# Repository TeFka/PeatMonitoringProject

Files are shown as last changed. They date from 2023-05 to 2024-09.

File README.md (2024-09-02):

# University group project
# Peat monitoring device
### This is the repository for used for storage of all relevant resources used for the university group project.<br>
### The project involved development of a device that would be placed in a peat and provides measuremetns about the peat state.</br>
### Measurements include:
* Surface elevation - shows how much peat surface changed water in it.</br>
* Water pressure - shows the pressure created by the peat water table.</br>
* Temperature - shows temperature of surroundings around the device.</br>
* Operate for at least 6 months unsupervised and store all data.</br>
### A poster was created for the device:</br>
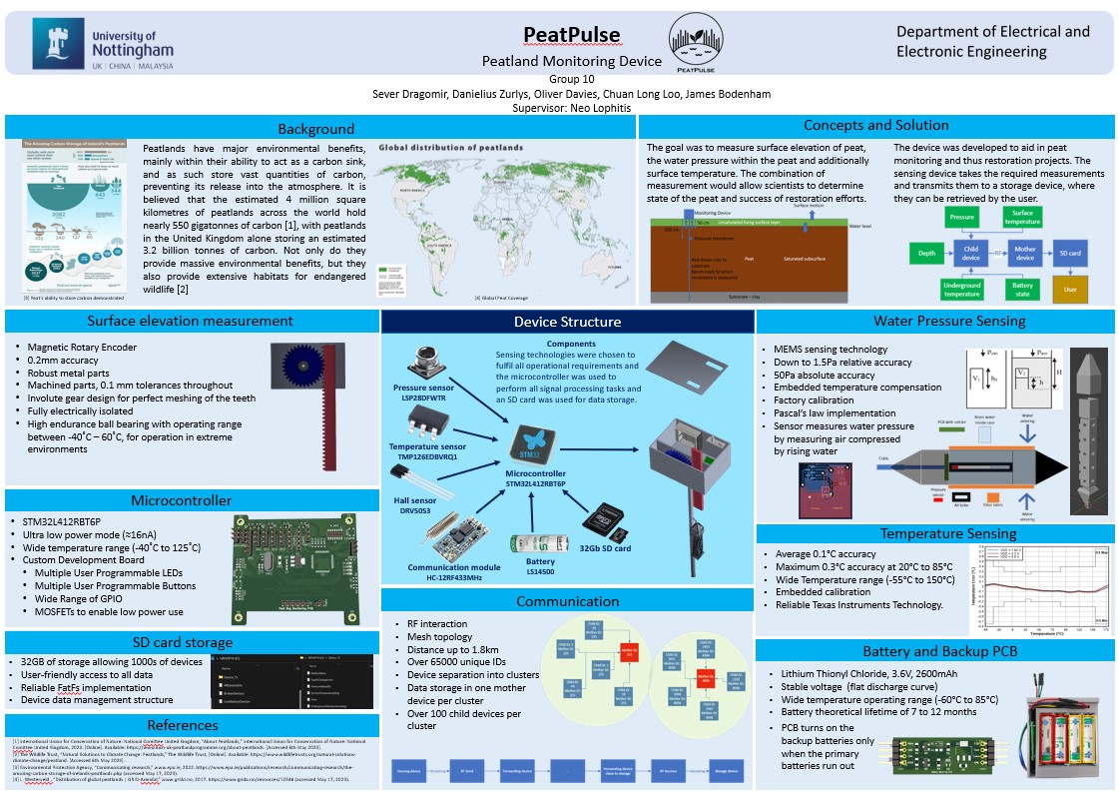
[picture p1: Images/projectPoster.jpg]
The poster of project
</br>
### The respository was created and managed by Danielius Zurlys. Project work done by Danielius Zurlys:<br>
* All embedded software<br>
* Hardware and mechanical designs for pressure sensor<br>
* Hardware and mechanical designs for temperature sensor<br>
### Work done by other group members:<br>
* Oliver Davies - Developed PCB for STM32<br>
* Chuan Loo - Developed PCB for battery control<br>
* Sever Dragomir - Design for main case and elevantion sensor.<br>
* James Bodenham - RF communication hardware choice and logic<br>

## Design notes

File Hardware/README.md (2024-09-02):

# All hardware designs</br>
### Contains all hardware designs which include:</br>
1. Pressure sensor PCB - the PCB is meant to simply host the used presssure sensor and provide easier connections for the user.</br>
2. Batter management system PCB (Created by Chuan Loo) - the battery system allows to reduce battery votlage to acceptable level and switch to the second battery once the first battery is depleted.</br>
3. STM32 PCB (Created by Oliver Davies) - a PCB meant to host the STM32 chip that would control the logic of the whole device.</br>

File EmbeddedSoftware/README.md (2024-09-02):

# All developed embedded software<br>
### Developed by Danielius Zurlys, while colaborating with other team members.<br>
The software is presented as the whole STM32 baord project or as a separate module meant to only cover one functionality of the overall device.

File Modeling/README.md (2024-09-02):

# All modelling work
The repository only includes pressure sensor designs, created by Danielius Zurlys, as other designs were not available.

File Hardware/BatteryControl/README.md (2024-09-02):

# Battery management PCB PCB</br>
### Designed by Chuan Loo</br>
### The PCB is meant to allow efficient and safew usage of batteries. Main functions are:</br>
* Reduce battery voltage to safe levels for the PCB.</br
* Use one battery at a time even if two are connected, when one battery is depleted, only then the PCB starts retrieving power from second battery.</br

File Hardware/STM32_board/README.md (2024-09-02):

# STM32 chip PCB</br>
Designed by Oliver Davies</br>
The main PCB for STM32 chip. Provides SPI, I2C, UART and analogue connections that allow communicaton with all relevant components. Connection to the battery is also availalbe to provide power.</br>

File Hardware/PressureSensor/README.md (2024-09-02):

# Pressure sensor PCB
Developed PCB to host pressure sensor. The used pressure sensor is LPS28DFW (.pdf datasheet file provded).
The sensor is very small and the PCB is meant to enable connection between sensor and standart connections.

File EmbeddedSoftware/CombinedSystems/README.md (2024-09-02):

# Combined STM32 projects<br>
### Covers combined projects, each involving several separate modules. The maind components are:<br>
* Code for Mother device - device meant for data storage.<br>
* Code for Child device - device meant for data grathering.<br>
* Code for remote connector - device meant for data retrieval.<br>
### The overall operation logic goes as follows:<br>
1. The child device gathers data using available sensors.<br>
2. The child device sends data to the mother device using RF communicaton, if the mother device is too far away, other device acts as a proxy.<br>
3. The mother devoce receives the data from child device and saves it into an SD card.<br>
4. The operation repeats itself at specific intervals and for a required amount of time.<br>
5. The user comes to the mother device and uses the remote device to communicate with mother device and the mother device transfers all stored data to the remote.<br>

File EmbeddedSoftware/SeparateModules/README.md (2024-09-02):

# Code for separate modules<br>
### Covers code for separate moduels that would then be used together, the modules include<br>
1. Depth measurement logic - logic for using analogue Hall magnet sensors for surface elevation measurements. The sensors would provide measurements from magnets on the elevation sensor and this way determine the current surface movement. The modeul code includes calibrartion values that are needed for accurate measurements.<br>
2. Pressure sensor interaction module - the code includes C wrapper for STM32 that allows to communicate with LPS28DFW pressure sensor using I2C. Covers all relevant operations an dinteractions with registers.<br>
3. Temperature sensor interaction module - the code includes C wrapper for STM32 that allows to communicate with TMP126-Q1 temperature sensor using I2C. Covers all relevant operations an dinteractions with registers.<br>
4. SD card interacttion module - the code allows to interact with an SD card using basic SPI commands. It is meant to work with FATFS support and can be used directly with a basic SD card adapter.<br>
5. STM32 flash memory inteaction module - the code allows to easilty interact with the STM32 flash memory and store data at specific locations.<br>
6. RF networking logic module - the code allows to automatically handle RF communication logic of the device system. The main feature is the ability for the device to act as a data proxy for another device and this way allowing devives to communicate with further devices. When device sends data, it also sends parameters that allow proxy devices to handle data correctly, such as target device or the number of bounces the data had. The module allows to create the communication network that the system needs.<br>

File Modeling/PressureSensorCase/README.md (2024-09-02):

# Pressure sensor mechanical designs
### Designs include:<br>
1. Direct case - a case that would allow the pressure sensor to sense the underground water pressure directly.<br>
2. Tube case - a case that would allow the pressure sensor to sense the water pressure using compressed air in a tube. The water would rise up the tube and compress the air in the tube, which would then be measured by the pressure sensor. The pressre of compressed air is equal to the water pressure applied at the end of the tube, therefore the approach can provide good results.<br>
<br>
The tube design has potential to increase logevity of the pressure sensor by avoiding the direct contact with acidic and hazardous peat environment, while direct design is simpler and more reliable.<br>

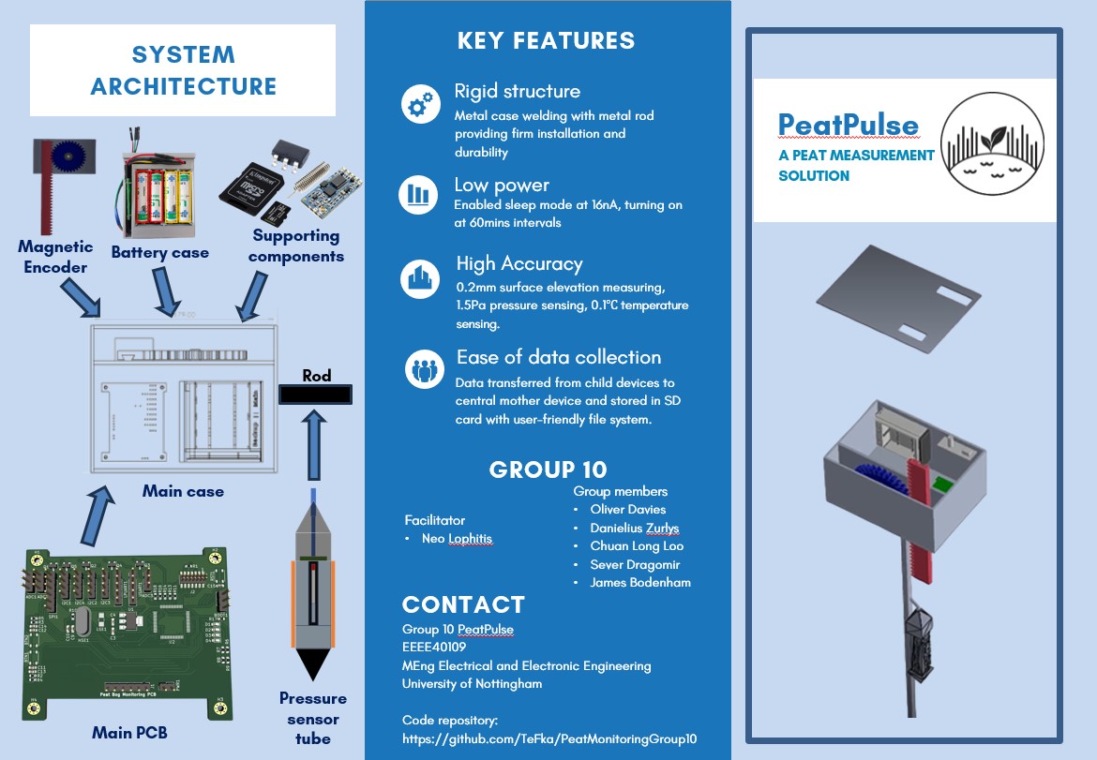
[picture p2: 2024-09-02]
Images/flyerFront.jpg

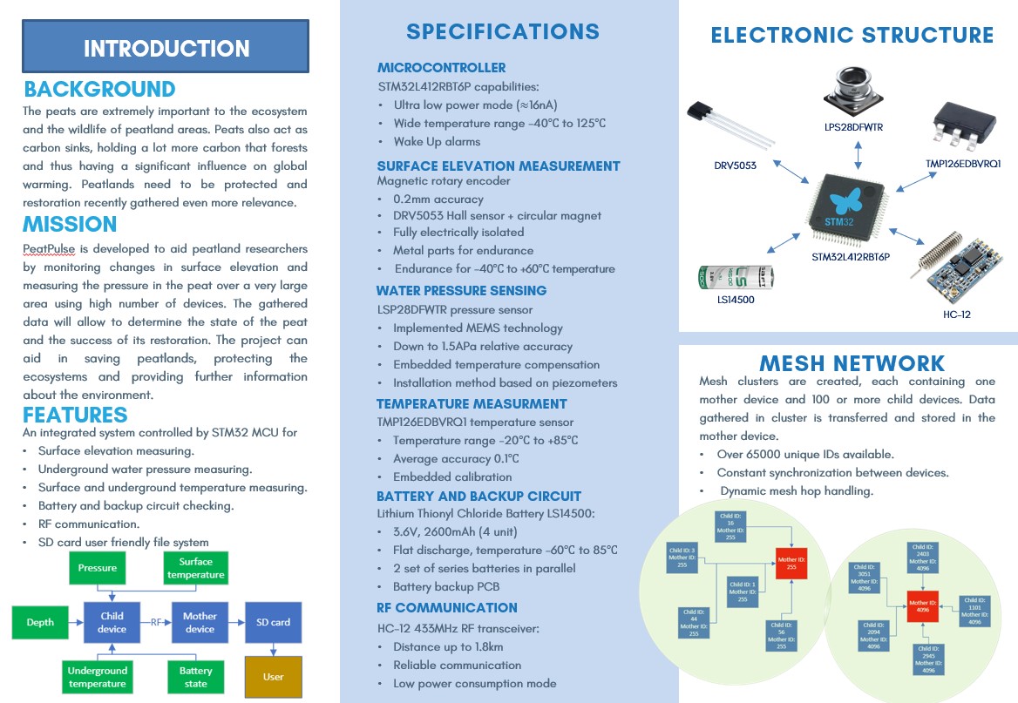
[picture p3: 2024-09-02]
Images/flyerBack.jpg

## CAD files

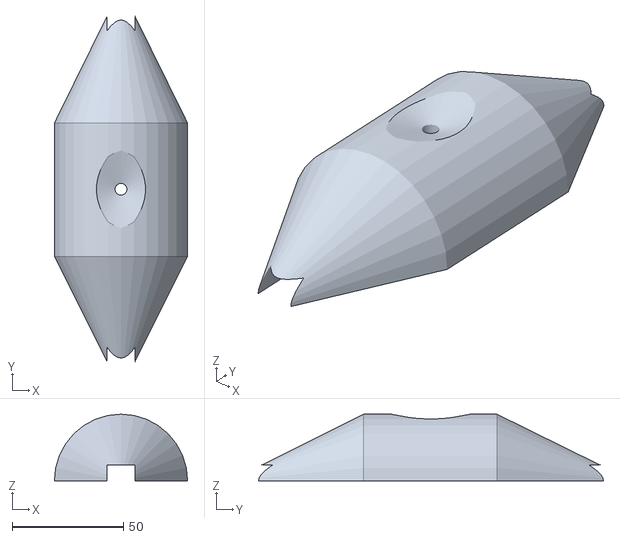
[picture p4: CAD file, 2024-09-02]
Modeling/PressureSensorCase/directCase/directCaseBack.stl
60.0 x 155.3 x 30.0

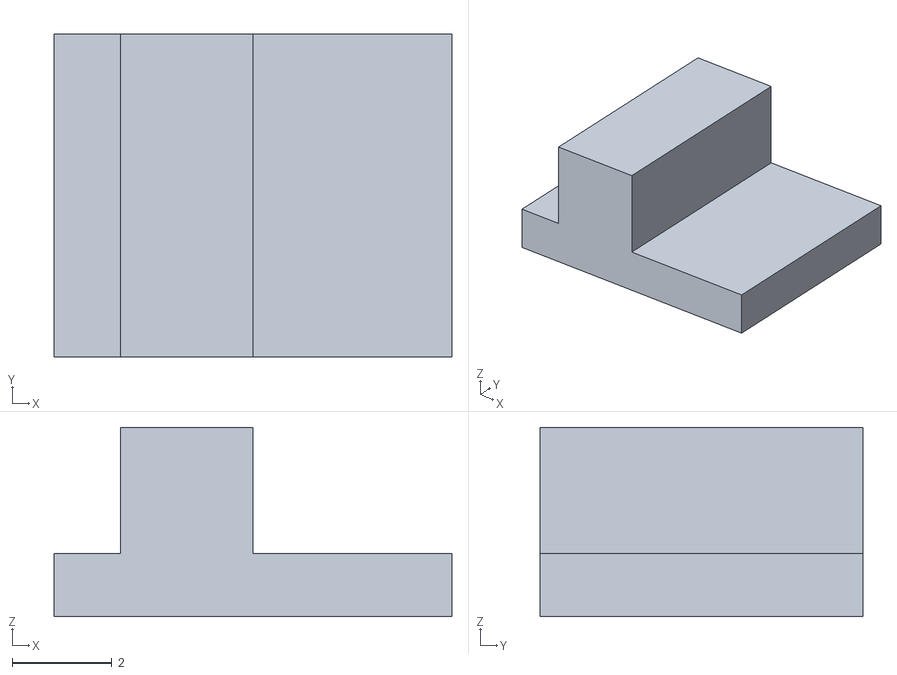
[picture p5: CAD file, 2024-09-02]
Modeling/PressureSensorCase/tubeCase/TubePCBHolder.stl
8.00 x 6.50 x 3.80

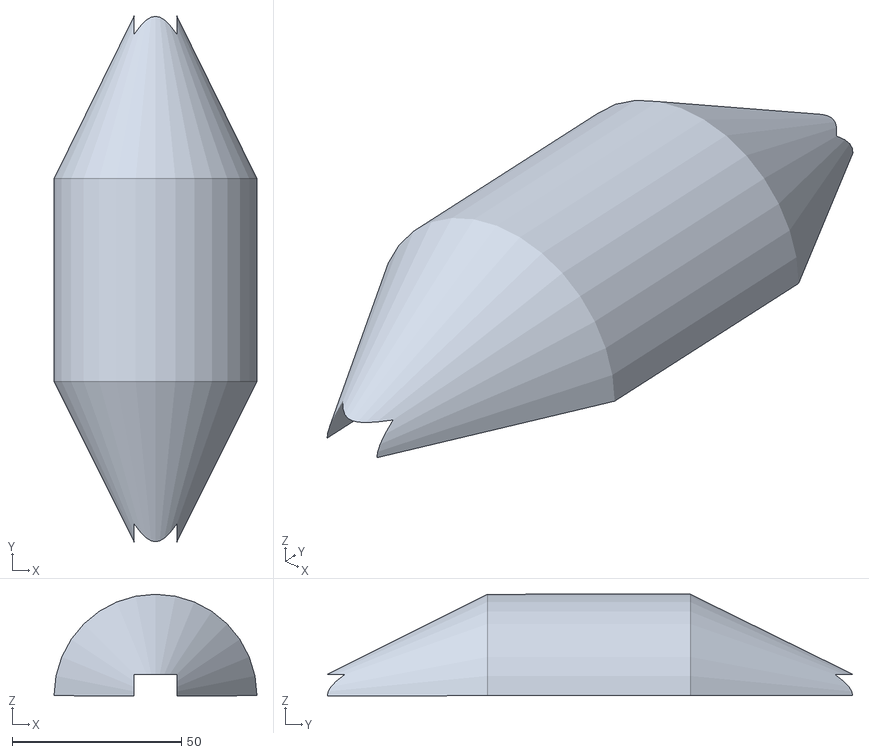
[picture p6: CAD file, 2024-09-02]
Modeling/PressureSensorCase/directCase/directCaseFront.stl
60.0 x 155.3 x 30.0

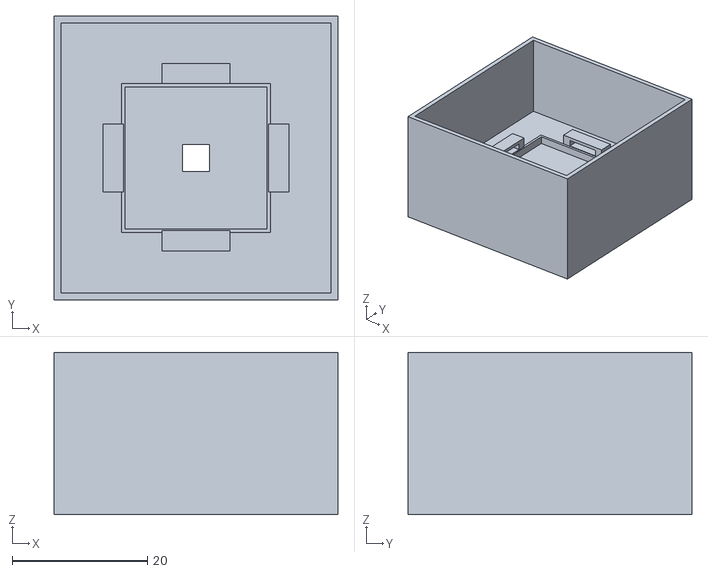
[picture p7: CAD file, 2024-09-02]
Modeling/PressureSensorCase/tubeCase/TubePCBArea.stl
42.0 x 42.0 x 24.0

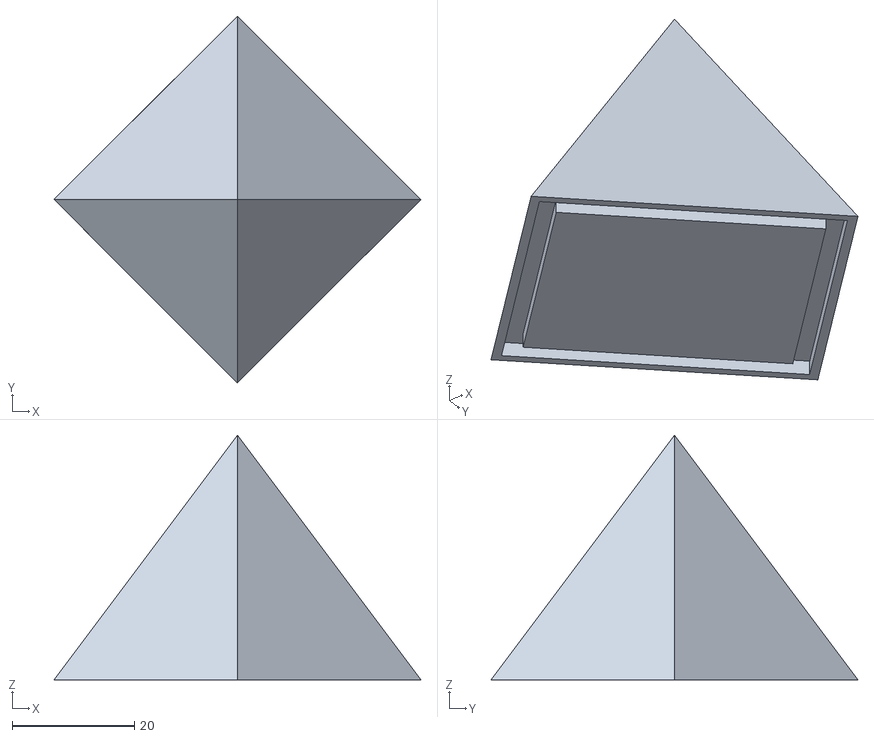
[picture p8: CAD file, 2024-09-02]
Modeling/PressureSensorCase/tubeCase/TubeSpike.stl
60.0 x 60.0 x 40.0

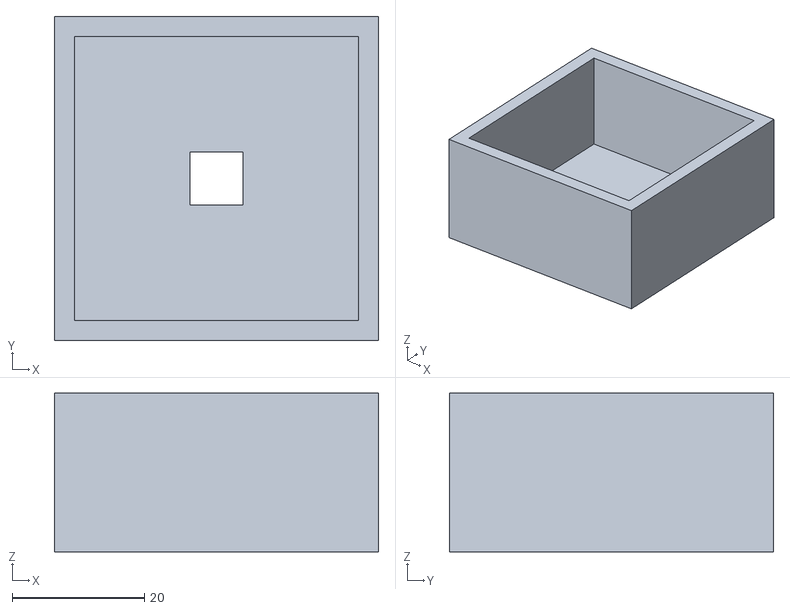
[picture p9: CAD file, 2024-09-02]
Modeling/PressureSensorCase/tubeCase/TubeCover.stl
49.0 x 49.0 x 24.0

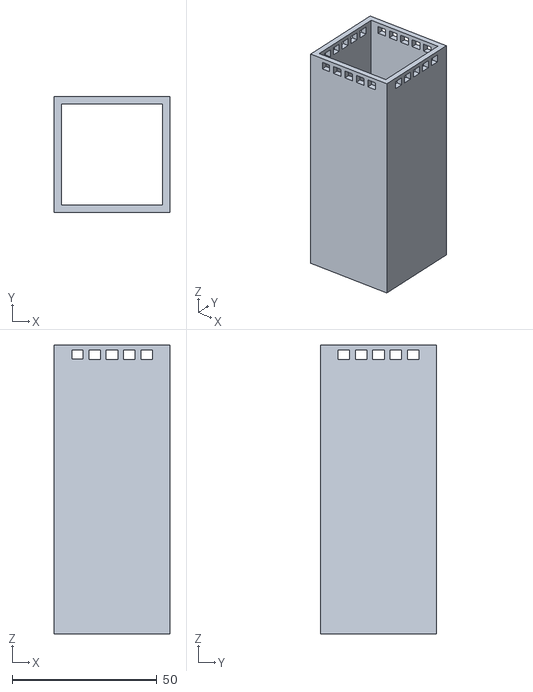
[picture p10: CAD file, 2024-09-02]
Modeling/PressureSensorCase/tubeCase/Tube.stl
40.0 x 40.0 x 100.0

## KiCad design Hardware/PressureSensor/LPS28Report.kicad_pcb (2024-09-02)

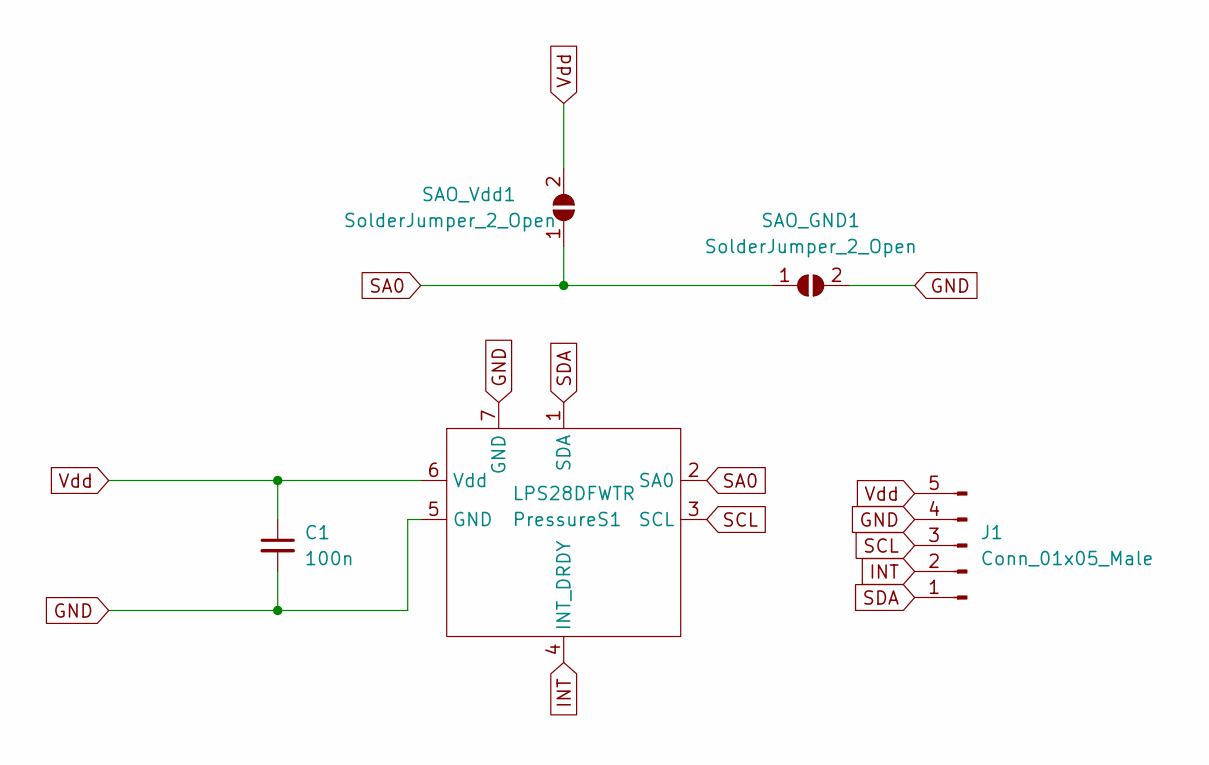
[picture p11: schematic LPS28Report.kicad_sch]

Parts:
C1: 100n; C_0603_1608Metric_Pad1.08x0.95mm_HandSolder
J1: Conn_01x05_Male; PinHeader_1x05_P1.00mm_Vertical_SMD_Pin1Left
PressureS1: LPS28DFWTR
SAO_GND1: SolderJumper_2_Open; SolderJumper-2_P1.3mm_Open_Pad1.0x1.5mm
SAO_Vdd1: SolderJumper_2_Open; SolderJumper-2_P1.3mm_Open_Pad1.0x1.5mm

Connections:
GND: C1.2, J1.4, PressureS1.5 (GND), PressureS1.7 (GND), SAO_GND1.2 (B)
INT: J1.2, PressureS1.4 (INT_DRDY)
SA0: PressureS1.2 (SA0), SAO_GND1.1 (A), SAO_Vdd1.1 (A)
SCL: J1.3, PressureS1.3 (SCL)
SDA: J1.1, PressureS1.1 (SDA)
Vdd: C1.1, J1.5, PressureS1.6 (Vdd), SAO_Vdd1.2 (B)

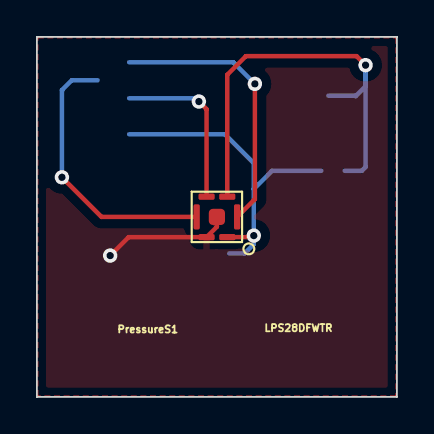
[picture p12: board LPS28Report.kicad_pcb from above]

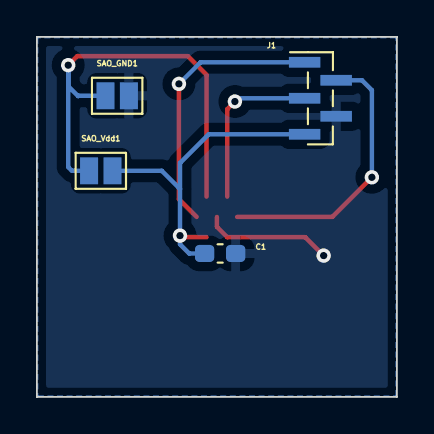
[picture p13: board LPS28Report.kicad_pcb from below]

Board: 2 copper layers, 20.0 x 20.0 mm, 5 parts (4 on the bottom side), 6 nets.

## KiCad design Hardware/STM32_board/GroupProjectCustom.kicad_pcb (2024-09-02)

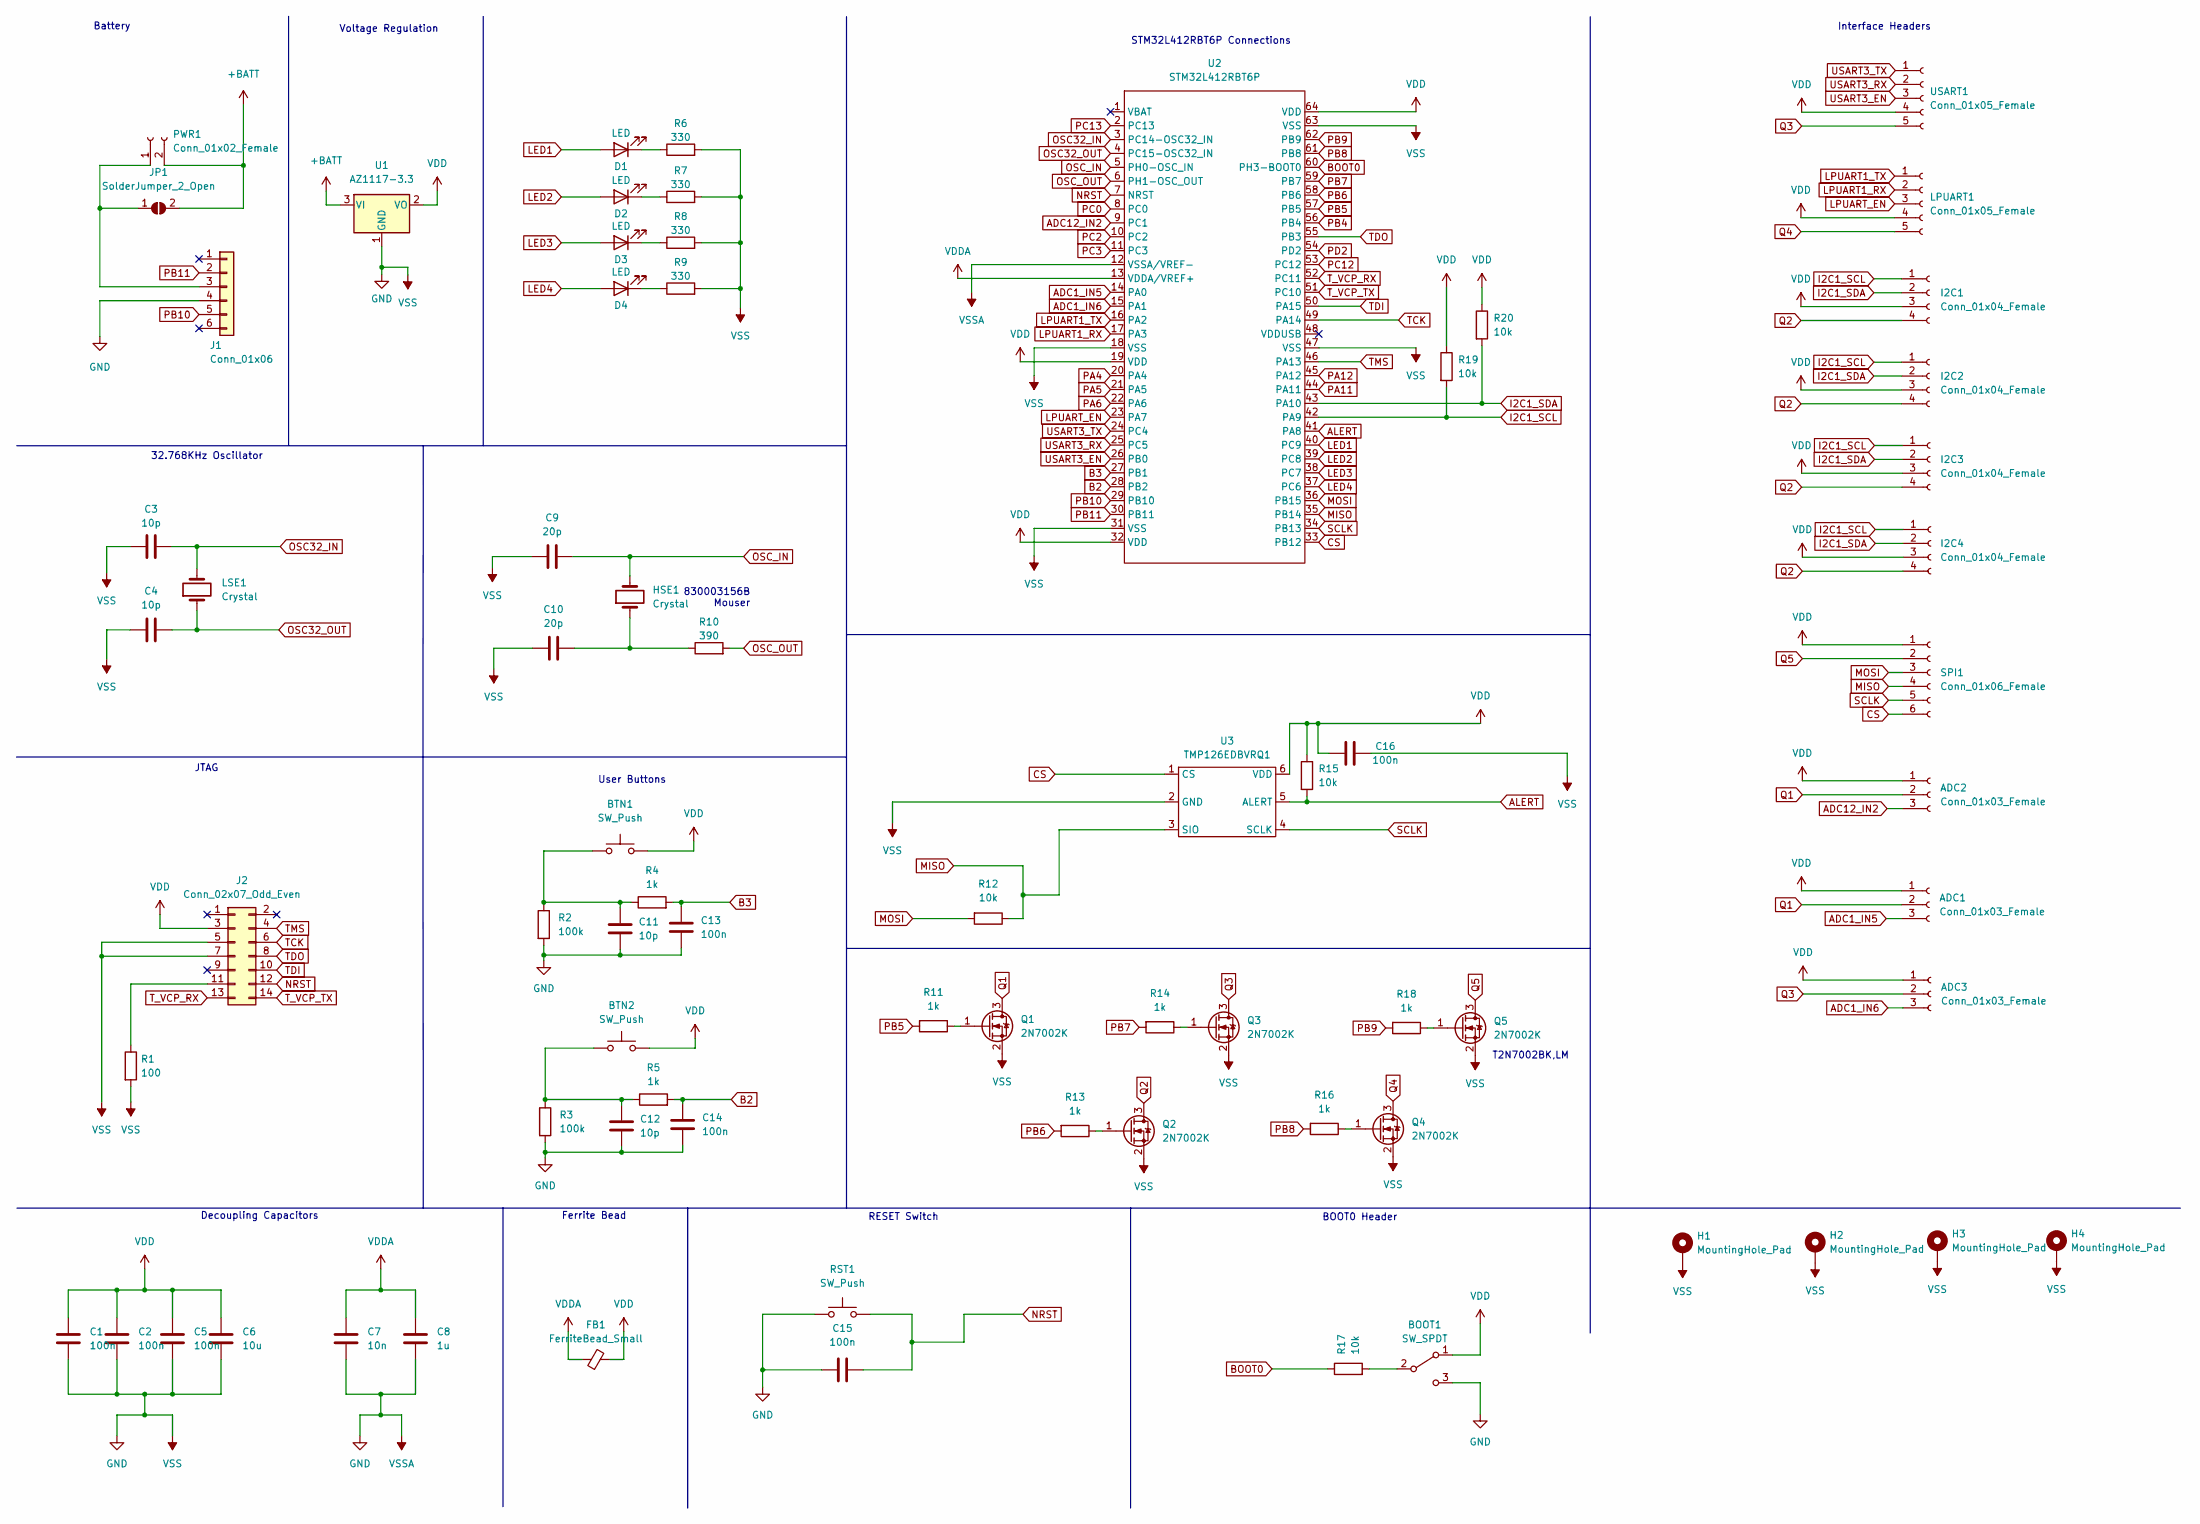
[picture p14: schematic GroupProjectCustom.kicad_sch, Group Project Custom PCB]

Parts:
ADC1, ADC2, ADC3: Conn_01x03_Female; PinHeader_1x03_P2.54mm_Vertical
BOOT1: SW_SPDT; PinHeader_1x03_P2.54mm_Vertical
BTN1, BTN2: SW_Push; SW_Push_1P1T_NO_Vertical_Wuerth_434133025816
C1, C2, C5, C13, C14, C15, C16: 100n; C_0603_1608Metric_Pad1.08x0.95mm_HandSolder
C3, C4, C11, C12: 10p; C_0603_1608Metric_Pad1.08x0.95mm_HandSolder
C6: 10u; C_0603_1608Metric_Pad1.08x0.95mm_HandSolder
C7: 10n; C_0603_1608Metric_Pad1.08x0.95mm_HandSolder
C8: 1u; C_0603_1608Metric_Pad1.08x0.95mm_HandSolder
C9, C10: 20p; C_0603_1608Metric_Pad1.08x0.95mm_HandSolder
D1, D2, D3, D4: LED; LED_0603_1608Metric_Pad1.05x0.95mm_HandSolder
FB1: FerriteBead_Small; R_0603_1608Metric_Pad0.98x0.95mm_HandSolder
H1, H2, H3, H4: MountingHole_Pad; MountingHole_2.2mm_M2_Pad_Via
HSE1: Crystal; Crystal_HC49-4H_Vertical
I2C1, I2C2, I2C3, I2C4: Conn_01x04_Female; PinHeader_1x04_P2.54mm_Vertical
J1: Conn_01x06; PinHeader_1x06_P2.54mm_Vertical
J2: Conn_02x07_Odd_Even; PinHeader_2x07_P1.27mm_Vertical_SMD
JP1: SolderJumper_2_Open; SolderJumper-2_P1.3mm_Open_TrianglePad1.0x1.5mm
LPUART1: Conn_01x05_Female; PinHeader_1x05_P2.54mm_Vertical
LSE1: Crystal; Crystal_SMD_MicroCrystal_CC7V-T1A-2Pin_3.2x1.5mm_HandSolder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
PWR1: Conn_01x02_Female; PinHeader_1x02_P2.54mm_Vertical
Q1, Q2, Q3, Q4, Q5: 2N7002K; SOT-23
R1: 100; R_0603_1608Metric
R2, R3: 100k; R_0603_1608Metric
R4, R5, R11, R13, R14, R16, R18: 1k; R_0603_1608Metric
R6, R7, R8, R9: 330; R_0603_1608Metric
R10: 390; R_0603_1608Metric
R12, R15, R17, R19, R20: 10k; R_0603_1608Metric
RST1: SW_Push; SW_Push_1P1T_NO_Vertical_Wuerth_434133025816
SPI1: Conn_01x06_Female; PinHeader_1x06_P2.54mm_Vertical
U1: AZ1117-3.3; SOT-223-3_TabPin2
U2: STM32L412RBT6P; STM32L412RBT6P_Foot
U3: TMP126EDBVRQ1; SOT-23-6_Handsoldering
USART1: Conn_01x05_Female; PinHeader_1x05_P2.54mm_Vertical

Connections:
+BATT: JP1.2 (B), PWR1.2, U1.3 (VI)
ADC1_IN5: ADC1.3, U2.14 (PA0)
ADC1_IN6: ADC3.3, U2.15 (PA1)
ADC12_IN2: ADC2.3, U2.9 (PC1)
ALERT: R15.2, U2.41 (PA8), U3.5 (ALERT)
B2: C14.1, R5.2, U2.28 (PB2)
B3: C13.1, R4.2, U2.27 (PB1)
BOOT0: R17.1, U2.60 (PH3-BOOT0)
CS: SPI1.6, U2.33 (PB12), U3.1 (CS)
GND: BOOT1.3 (C), C1.2, C2.2, C3.1, C4.1, C5.2, C6.2, C7.2, C8.2, C9.1, C10.1, C11.1, C12.1, C13.2, C14.2, C15.1, C16.2, H1.1, H2.1, H3.1, H4.1, J1.4, J2.5, J2.7, Q1.2 (S), Q2.2 (S), Q3.2 (S), Q4.2 (S), Q5.2 (S), R1.2, R2.2, R3.2, R6.2, R7.2, R8.2, R9.2, RST1.1, U1.1 (GND), U2.12 (VSSA/VREF-), U2.18 (VSS), U2.31 (VSS), U2.47 (VSS), U2.63 (VSS), U3.2 (GND)
I2C1_SCL: I2C1.1, I2C2.1, I2C3.1, I2C4.1, R19.2, U2.42 (PA9)
I2C1_SDA: I2C1.2, I2C2.2, I2C3.2, I2C4.2, R20.2, U2.43 (PA10)
LED1: D1.2 (A), U2.40 (PC9)
LED2: D2.2 (A), U2.39 (PC8)
LED3: D3.2 (A), U2.38 (PC7)
LED4: D4.2 (A), U2.37 (PC6)
LPUART1_RX: LPUART1.2, U2.17 (PA3)
LPUART1_TX: LPUART1.1, U2.16 (PA2)
LPUART_EN: LPUART1.3, U2.23 (PA7)
MISO: R12.1, SPI1.4, U2.35 (PB14), U3.3 (SIO)
MOSI: R12.2, SPI1.3, U2.36 (PB15)
NRST: C15.2, J2.12, RST1.2, U2.7 (NRST)
unnamed: BOOT1.2 (B), R17.2
unnamed: BTN1.1, C11.2, R2.1, R4.1
unnamed: BTN2.1, C12.2, R3.1, R5.1
unnamed: C10.2, HSE1.1, R10.1
unnamed: D1.1 (K), R6.1
unnamed: D2.1 (K), R7.1
unnamed: D3.1 (K), R8.1
unnamed: D4.1 (K), R9.1
unnamed: J1.3, JP1.1 (A), PWR1.1
unnamed: J2.11, R1.1
unnamed: Q1.1 (G), R11.1
unnamed: Q2.1 (G), R13.1
unnamed: Q3.1 (G), R14.1
unnamed: Q4.1 (G), R16.1
unnamed: Q5.1 (G), R18.1
OSC32_IN: C3.2, LSE1.2, U2.3 (PC14-OSC32_IN)
OSC32_OUT: C4.2, LSE1.1, U2.4 (PC15-OSC32_IN)
OSC_IN: C9.2, HSE1.2, U2.5 (PH0-OSC_IN)
OSC_OUT: R10.2, U2.6 (PH1-OSC_OUT)
PA4: U2.20 (PA4)
PA5: U2.21 (PA5)
PA6: U2.22 (PA6)
PA11: U2.44 (PA11)
PA12: U2.45 (PA12)
PB4: U2.56 (PB4)
PB5: R11.2, U2.57 (PB5)
PB6: R13.2, U2.58 (PB6)
PB7: R14.2, U2.59 (PB7)
PB8: R16.2, U2.61 (PB8)
PB9: R18.2, U2.62 (PB9)
PB10: J1.5, U2.29 (PB10)
PB11: J1.2, U2.30 (PB11)
PC0: U2.8 (PC0)
PC2: U2.10 (PC2)
PC3: U2.11 (PC3)
PC12: U2.53 (PC12)
PC13: U2.2 (PC13)
PD2: U2.54 (PD2)
Q1: ADC1.2, ADC2.2, Q1.3 (D)
Q2: I2C1.4, I2C2.4, I2C3.4, I2C4.4, Q2.3 (D)
Q3: ADC3.2, Q3.3 (D), USART1.5
Q4: LPUART1.5, Q4.3 (D)
Q5: Q5.3 (D), SPI1.2
SCLK: SPI1.5, U2.34 (PB13), U3.4 (SCLK)
TCK: J2.6, U2.49 (PA14)
TDI: J2.10, U2.50 (PA15)
TDO: J2.8, U2.55 (PB3)
TMS: J2.4, U2.46 (PA13)
T_VCP_RX: J2.13, U2.52 (PC11)
T_VCP_TX: J2.14, U2.51 (PC10)
USART3_EN: U2.26 (PB0), USART1.3
USART3_RX: U2.25 (PC5), USART1.2
USART3_TX: U2.24 (PC4), USART1.1
VDD: ADC1.1, ADC2.1, ADC3.1, BOOT1.1 (A), BTN1.2, BTN2.2, C1.1, C2.1, C5.1, C6.1, C16.1, FB1.2, I2C1.3, I2C2.3, I2C3.3, I2C4.3, J2.3, LPUART1.4, R15.1, R19.1, R20.1, SPI1.1, U1.2 (VO), U2.19 (VDD), U2.32 (VDD), U2.64 (VDD), U3.6 (VDD), USART1.4
VDDA: C7.1, C8.1, FB1.1, U2.13 (VDDA/VREF+)

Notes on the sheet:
RESET Switch
JTAG
BOOT0 Header
Ferrite Bead
User Buttons
STM32L412RBT6P Connections
Interface Headers
Decoupling Capacitors
Voltage Regulation
Battery
32.768KHz Oscillator
830003156B Mouser
T2N7002BK,LM

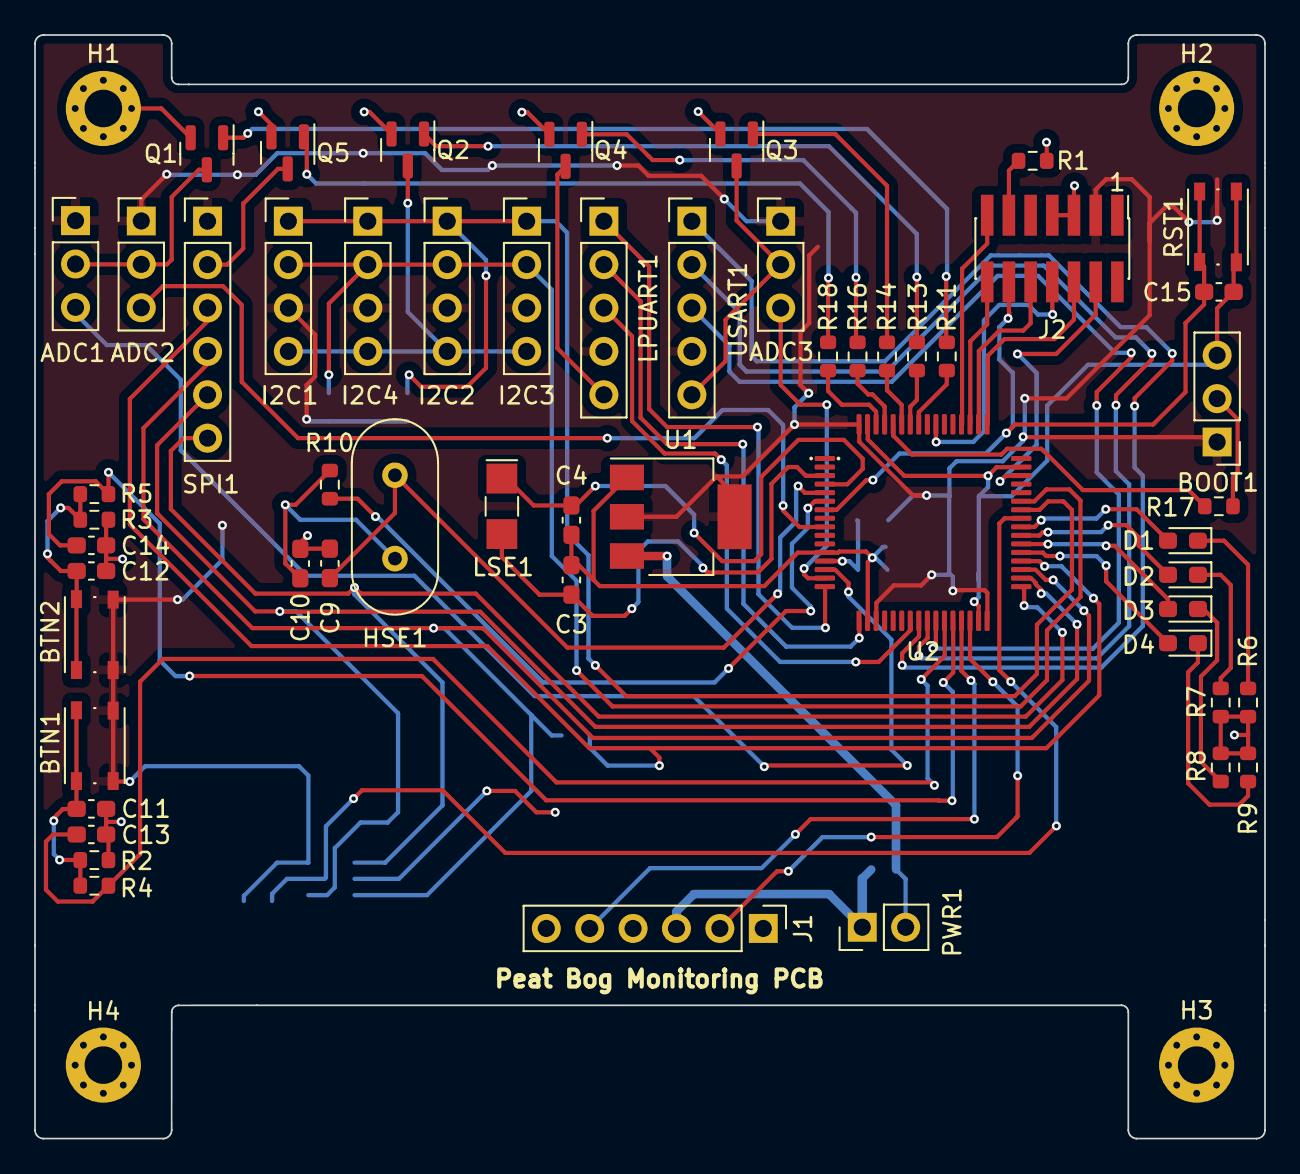
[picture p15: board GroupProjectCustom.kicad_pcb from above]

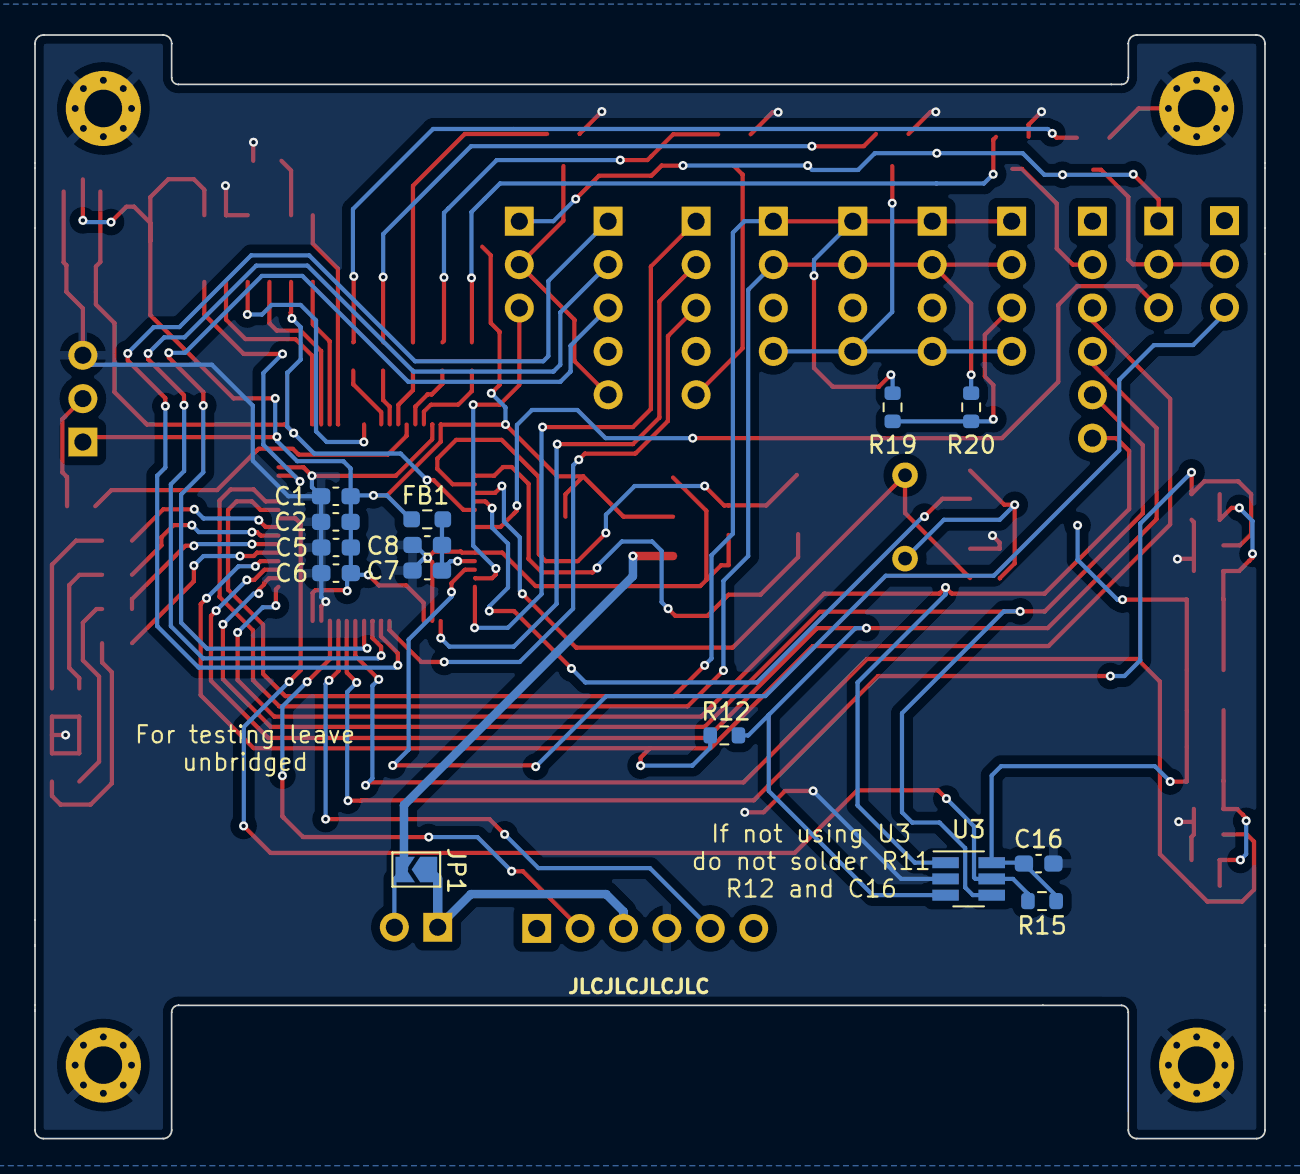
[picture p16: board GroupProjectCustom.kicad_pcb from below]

Board: 2 copper layers, 72.0 x 64.6 mm, 73 parts (14 on the bottom side), 65 nets.

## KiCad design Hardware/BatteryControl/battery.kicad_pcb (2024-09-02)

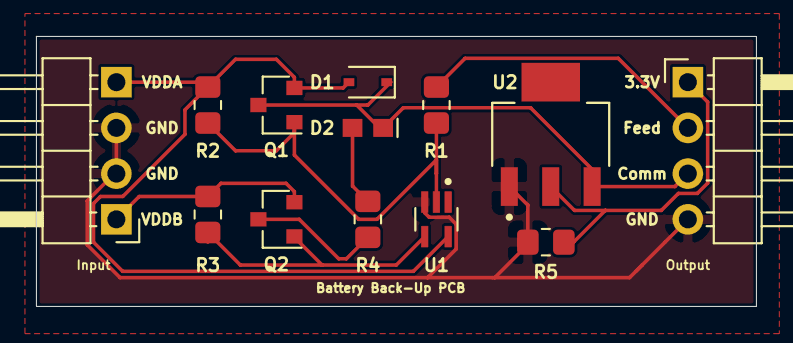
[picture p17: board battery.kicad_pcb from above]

Board: 2 copper layers, 40.0 x 15.0 mm, 13 parts (0 on the bottom side), 10 nets.

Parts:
D1: 1N4148WS; D_SOD-323
D2: RED; 0603_DIODE
Input: Conn_01x04_Male; PinHeader_1x04_P2.54mm_Horizontal
Output: Conn_01x04_Male; PinHeader_1x04_P2.54mm_Horizontal
Q1, Q2: IRLML6402; SOT-23
R1: 825; R_0805_2012Metric_Pad1.20x1.40mm_HandSolder
R2, R3, R5: 10k; R_0805_2012Metric_Pad1.20x1.40mm_HandSolder
R4: 200; R_0805_2012Metric_Pad1.20x1.40mm_HandSolder
U1: 74AHC1G04; SOT65P210X110-5N
U2: LM1117-3.3; VREG_LM1117MP-3.3_NOPB

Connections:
3.3V: Output.1, R5.1, U2.2
Comm: D1.1, D2.1, Output.3, Q1.3, U2.3
Feed: Output.2, R1.2
GND: Input.2, Input.3, Output.4, R5.2, U1.3, U2.1
unnamed: D2.2, R4.1
unnamed: Q1.1, R1.1, R2.2, U1.2
unnamed: Q2.1, R3.1, U1.4
unnamed: Q2.3, R4.2
VDDA: D1.2, Input.4, Q1.2, R2.1, U1.5
VDDB: Input.1, Q2.2, R3.2

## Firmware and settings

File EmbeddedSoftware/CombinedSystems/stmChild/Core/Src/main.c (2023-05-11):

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
/* Includes ------------------------------------------------------------------*/
#include "main.h"

/* USER CODE BEGIN Includes */
#include "retarget.h"
#include <ManagementChild.h>
#include <stdio.h>
#include <stdlib.h>
#include "UnitTests.h"
#include <RF/comms.h>

//#include <LCD/LiquidCrystal.h>
/* USER CODE END Includes */

ADC_HandleTypeDef hadc1;
ADC_HandleTypeDef hadc2;

I2C_HandleTypeDef hi2c1;

UART_HandleTypeDef hlpuart1;
UART_HandleTypeDef huart3;

RNG_HandleTypeDef hrng;

RTC_HandleTypeDef hrtc;

SPI_HandleTypeDef hspi2;

void SystemClock_Config(void);
static void MX_GPIO_Init(void);
static void MX_RTC_Init(void);
static void MX_I2C1_Init(void);
static void MX_RNG_Init(void);
static void MX_LPUART1_UART_Init(void);
static void MX_SPI2_Init(void);
static void MX_USART3_UART_Init(void);
static void MX_ADC1_Init(void);
static void MX_ADC2_Init(void);
/* USER CODE BEGIN 0 */
struct Queue RXFIFO;
uint8_t UART2_rxBuffer[20];
/* USER CODE END 0 */

/**
  * @brief  The application entry point.
  * @retval int
  */
int main(void)
{
  /* USER CODE BEGIN 1 */

	struct CommunicationHandles handles;
	handles.SPIhandle = &hspi2;
	handles.UARThandle = &hlpuart1;
	handles.ADChandle1 = &hadc1;
	handles.ADChandle2 = &hadc2;
	handles.I2Chandle = &hi2c1;
	handles.RTChandle = &hrtc;

  /* USER CODE END 1 */

  /* MCU Configuration--------------------------------------------------------*/

  /* Reset of all peripherals, Initializes the Flash interface and the Systick. */
  HAL_Init();

  /* Configure the system clock */
  SystemClock_Config();

  /* Initialize all configured peripherals */
  MX_GPIO_Init();
  MX_RTC_Init();
  MX_I2C1_Init();
  MX_RNG_Init();
  MX_LPUART1_UART_Init();
  MX_SPI2_Init();
  MX_USART3_UART_Init();
  MX_ADC1_Init();
  MX_ADC2_Init();
  /* USER CODE BEGIN 2 */
  RetargetInit(&huart3);

  HAL_UART_Receive_IT(&hlpuart1, UART2_rxBuffer, MSG_SIZE_TRANSFER);

  //HAL_Delay(100);
  struct rfDataStorage rfData;
  rfData.RXFIFO = &RXFIFO;
  if(mainSetup(&rfData, &handles)){
  	  mainOperation(&rfData, &handles);
  }

  HAL_GPIO_WritePin(GPIOC, GPIO_PIN_6, GPIO_PIN_SET);
  HAL_GPIO_WritePin(GPIOC, GPIO_PIN_7, GPIO_PIN_SET);
  HAL_GPIO_WritePin(GPIOC, GPIO_PIN_8, GPIO_PIN_SET);
  HAL_GPIO_WritePin(GPIOC, GPIO_PIN_9, GPIO_PIN_SET);
  //depth test
  struct DepthData depthData;
  depthData.pos = 0;
  depthData.output1 = 0;
  depthData.output2 = 0;
  depthData.max_value_1 = 0;
  depthData.min_value_1 = 0;
  depthData.max_value_2 = 0;
  depthData.min_value_2 = 0;
  /* USER CODE END 2 */

  /* Infinite loop */
  /* USER CODE BEGIN WHILE */
  while (1)
  {
	  //Im_Here(&rfData);
    /* USER CODE END WHILE */

    /* USER CODE BEGIN 3 */

	  /*HAL_GPIO_WritePin(spiGPIO, spiGPIOPin, GPIO_PIN_SET);
	  HAL_Delay(100);
	  SDcardTest();
	  HAL_GPIO_WritePin(spiGPIO, spiGPIOPin, GPIO_PIN_RESET);

	  flashTest();

	  HAL_GPIO_WritePin(spiGPIO, spiGPIOPin, GPIO_PIN_SET);
	  HAL_Delay(100);
	  TemperatureTest(&hspi2);
	  HAL_GPIO_WritePin(spiGPIO, spiGPIOPin, GPIO_PIN_RESET);

	  HAL_GPIO_WritePin(uartGPIO, uartGPIOPin, GPIO_PIN_SET);
	  HAL_Delay(100);
	  rfTest(&hlpuart1);
	  HAL_GPIO_WritePin(uartGPIO, uartGPIOPin, GPIO_PIN_RESET);

	  HAL_GPIO_WritePin(i2cGPIO, i2cGPIOPin, GPIO_PIN_SET);
	  HAL_Delay(100);
	  pressureTest(&hi2c1, LPS28DFW_I2C_ADDRESS_DEFAULT);
	  pressureTest(&hi2c1, LPS28DFW_I2C_ADDRESS_SECONDARY);
	  HAL_GPIO_WritePin(i2cGPIO, i2cGPIOPin, GPIO_PIN_RESET);
	  //mainOperation(&rfData, &handles);
	  HAL_GPIO_WritePin(adcGPIO, adcGPIOPin, GPIO_PIN_SET);
	  HAL_Delay(100);
	  depthTest(&hadc1, &hadc2, &depthData);
	  HAL_GPIO_WritePin(adcGPIO, adcGPIOPin, GPIO_PIN_RESET);*

	  HAL_GPIO_WritePin(adcGPIO, adcGPIOPin, GPIO_PIN_SET);
	  HAL_Delay(100);
	  batteryTest(&hadc1);
	  HAL_GPIO_WritePin(adcGPIO, adcGPIOPin, GPIO_PIN_RESET);
*/
	  printf("\r\nLoop");

	  HAL_Delay(100);
  }
  /* USER CODE END 3 */
}

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
/* USER CODE BEGIN 4 */
void HAL_UART_RxCpltCallback(UART_HandleTypeDef *huart)
{
	//printf("\r\nreceived uart message");
	for (int i = 0; i < MSG_SIZE_TRANSFER; i++)
	{
			printf("\r\nreceived uart message: %x", UART2_rxBuffer[i]);
			enqueue(&RXFIFO, UART2_rxBuffer[i]);
	}
	//Setup new receive interrupt
	HAL_UART_Receive_IT(&hlpuart1, UART2_rxBuffer, MSG_SIZE_TRANSFER);

	//Abort new interrupt to clear the buffer
	HAL_UART_Abort_IT(&hlpuart1);

	//Setup new clean receive interrupt
	HAL_UART_Receive_IT(&hlpuart1, UART2_rxBuffer, MSG_SIZE_TRANSFER);
}
/* USER CODE END 4 */
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


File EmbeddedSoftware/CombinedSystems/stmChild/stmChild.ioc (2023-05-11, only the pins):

Mcu.UserName=STM32L412RBTxP
PA0.Signal=ADCx_IN5
PA1.Signal=ADCx_IN6
PA10.Signal=I2C1_SDA
PA2.Signal=LPUART1_TX
PA3.Signal=LPUART1_RX
PA7.Signal=GPIO_Output
PA9.Signal=I2C1_SCL
PB0.Signal=GPIO_Output
PB1.Signal=GPIO_Input
PB11.Signal=USART3_RX
PB12.Signal=GPIO_Output
PB13.Signal=SPI2_SCK
PB14.Signal=SPI2_MISO
PB15.Signal=SPI2_MOSI
PB2.Signal=GPIO_Input
PB5.Signal=GPIO_Output
PB6.Signal=GPIO_Output
PB7.Signal=GPIO_Output
PB8.Signal=GPIO_Output
PB9.Signal=GPIO_Output
PC1.Signal=ADCx_IN2
PC4.Signal=USART3_TX
PC6.Signal=GPIO_Output
PC7.Signal=GPIO_Output
PC8.Signal=GPIO_Output
PC9.Signal=GPIO_Output

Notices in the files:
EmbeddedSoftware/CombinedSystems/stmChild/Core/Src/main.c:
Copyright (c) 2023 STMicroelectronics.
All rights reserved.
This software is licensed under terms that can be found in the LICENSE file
